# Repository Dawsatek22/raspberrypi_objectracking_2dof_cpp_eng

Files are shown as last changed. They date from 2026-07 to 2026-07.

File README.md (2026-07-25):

# raspberrypi_objectracking_2dof_cpp_eng
The second version of a Raspberry Pi c++ object tracking robot(link is here: https://github.com/Dawsatek22/raspberrypi_objectracking_1dof_cpp). This version  can now use the x and y direction.The tutorial videos are posted 1 month earlier on c/c++ exclusive on : https://vanillo.tv/v/18WrPnBuGD-. first before it is posted on youtube in 26 august: https://youtu.be/UmCWkWiB-DA.It is advised to read the eng_list.txt first before following the tutorial video instructions.

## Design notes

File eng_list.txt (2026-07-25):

playlist tutorial video:
00:05: Warnings and summaries
00:10 assembeling the board:
03:14 add the camera module
03:51 add the servo board
05:21 add the servos
15:31 Attach camera
16:56 Attach wires
18:58 turn on the power
19:34 test the robot
22:52  Finishing the robot

Warnings and summaries:

This is a english list for the Raspberry Pi 2 degrees of freedom tracking robot in c++ language,Most of the cad parts used are also possible(and more)at: https://openroboticplatform.com/ .if you are interested,Links for  tools and materials are more for reference than a nessecary link,
You can find the required tools else if you want,
The tutorial video instructions is explained in text so take that in mind,
If there is something wrong please reply if possible.

Required software:

opencv c++ version for the Raspberry Pi ( https://opencv.org/get-started/?utm_source=opcv&utm_medium=home ),lccv for Raspberry Pi camera ( https://github.com/kbarni/LCCV.git ),
PIPCA9685 software for the Raspberry Pi ( https://github.com/barulicm/PiPCA9685.git ),
vnc viewer for pc/laptop ( https://www.realvnc.com/en/connect/download/viewer/?lai_sr=0-4&lai_sl=l&lai_p=1&lai_na=488119 ),
vscode or other editor for c++ and cmake and Raspberry Pi (optional).
Recomended skills:
c/c++ programming,ssh into a Raspberry Pi with vnc viewer,
using opencv in c++,Aquiring 3d printed parts or making parts,
screwing parts together.Working with 5V power supplies.

1x pc/laptop
1x wifi access
1x micro sd card with Raspberry Pi os installed(newest recommended).
2x MG9685R servo motor ( https://www.google.com/aclk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 ).
1x Raspberry Pi 4 power supply ( https://www.kiwi-electronics.com/nl/raspberry-pi-boards-behuizingen-uitbreidingen-en-accessoires-59/raspberry-pi-45w-usb-c-power-supply-wit-eu-20344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 ).
1x Raspberry Pi 4 4gb or more board ( https://www.kiwi-electronics.com/nl/raspberry-pi-boards-behuizingen-uitbreidingen-en-accessoires-59/raspberry-pi-4-model-b-4gb-4268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 ).
1x Raspberry Pi camera module 2 ( https://www.kiwi-electronics.com/nl/raspberry-pi-boards-behuizingen-uitbreidingen-en-accessoires-59/raspberry-pi-camera-accessoires-133/raspberry-pi-camera-module-2-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 ).
1x Raspberry Pi Camera and Display Cable - 15 pin FFC flex - 30cm (https://www.tinytronics.nl/en/cables-and-connectors/cables-and-adapters/ffc/raspberry-pi-camera-cable-15-pin-fpc-flex-30cm).
1x Servo Driver HAT for Raspberry Pi - 16ch - 12-bit - I2C or PCA9685 board as alernative  ( https://www.kiwi-electronics.com/en/servo-driver-hat-for-raspberry-pi-16ch-12-bit-i2c-10373?country=NL ).
6x 20mm m/f dupont wires ( https://www.amazon.nl/Dupont-Jumper-Arduino-Raspberry-projects/dp/B09KGRM98K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 )
1x yellow object for testing like a dc tt motor wheel for example( https://www.tinytronics.nl/en/mechanics-and-actuators/parts/wheels/spare-wheel-auto-kit-diy )
1x m2.5 allen wrench
1x m3 allen wrench
1x m4 allen wr

Screws and bolts spacer:
4x m3x14mm allen screws
4x m4 nuts
2x m3x6mm allen screws

2x m3x12mm allen screws
10x m3x16mm allen screws
10 m3 nuts
4x m2.5x6mm allen screws
2x m2.5x10x6 standoff brass spacer
2x m2x8mm allen screws2x m2 nuts

Cad parts(pla recomended):
1x dt22-225-d22_cam_plate_100x160mm.stl
1x dt22-226-cam_2-sideways.stl
1x dt22-241-mg996r_bottomv3_ext1.stl
1x dt22-241-orp_extender_bend_v3.2.stl
1x dt22-241-orp_extender60mm_mg996r_v3.stl
1x dt22-241-mg996r_bottom_v3.stl
1x Radek_Janecka-172-RaspberryPi_holder.stl

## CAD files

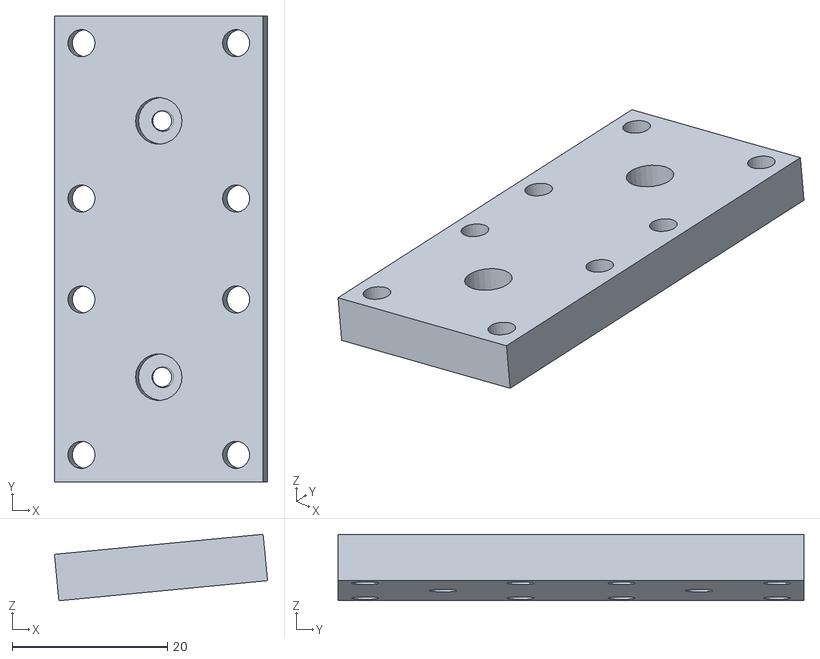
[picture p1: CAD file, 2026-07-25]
cad_parts/dt22-241-orp_extender60mm_mg996r_v3.stl
27.5 x 60.0 x 8.56

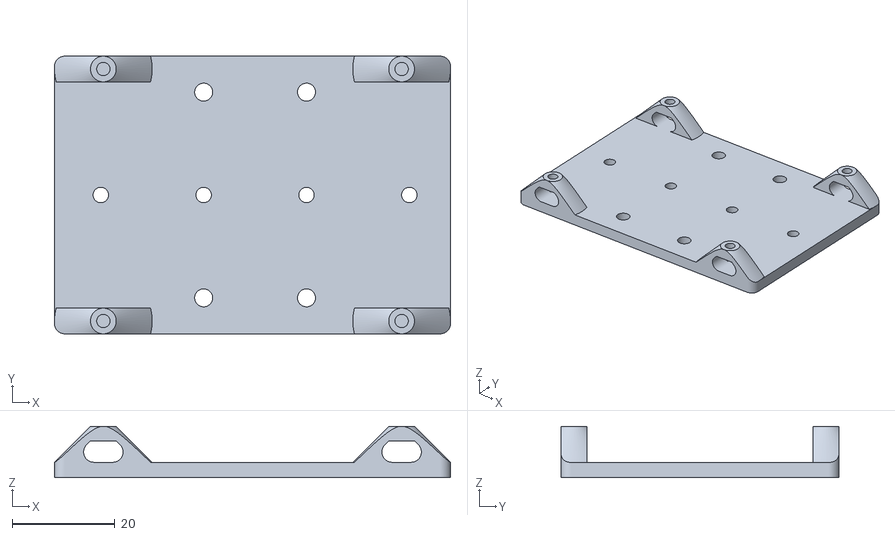
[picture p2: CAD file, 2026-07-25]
cad_parts/Radek_Janecka-172-RaspberryPi_holder.stl
77.0 x 54.0 x 10.0

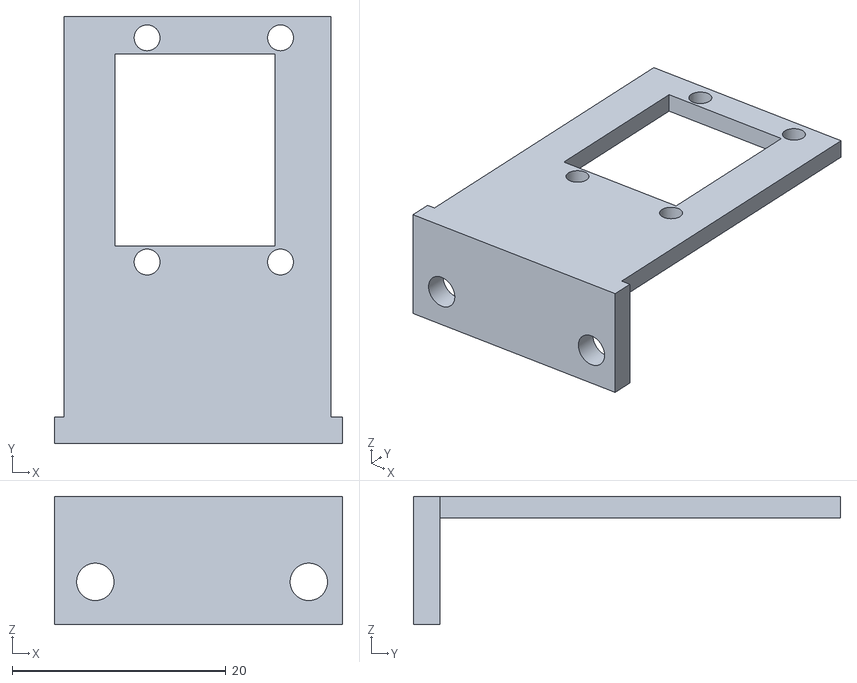
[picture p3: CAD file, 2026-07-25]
cad_parts/dt22-226-cam_2-sideways.stl
27.0 x 40.0 x 12.0

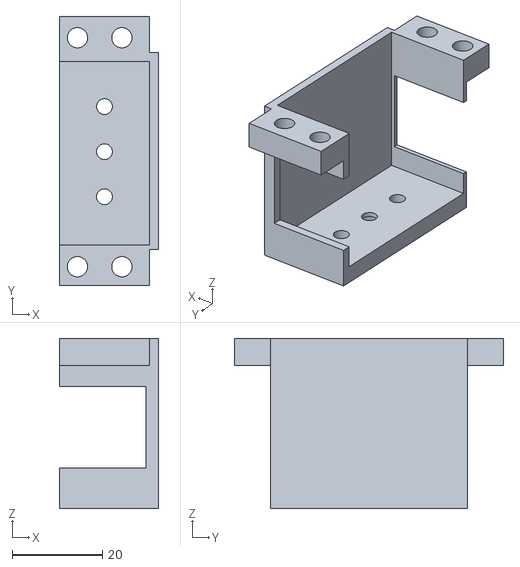
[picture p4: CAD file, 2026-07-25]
cad_parts/dt22-241-mg996r_bottom_v3.stl
22.0 x 59.7 x 37.7

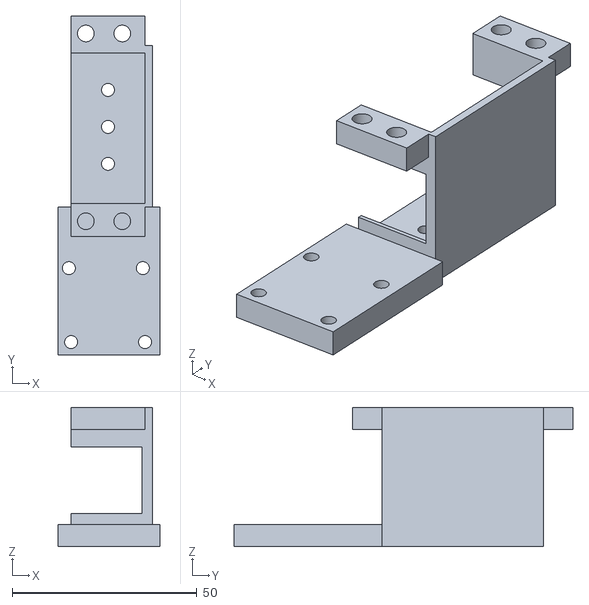
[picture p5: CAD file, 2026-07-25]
cad_parts/dt22-241-mg996r_bottomv3_ext1.stl
27.5 x 91.7 x 37.7

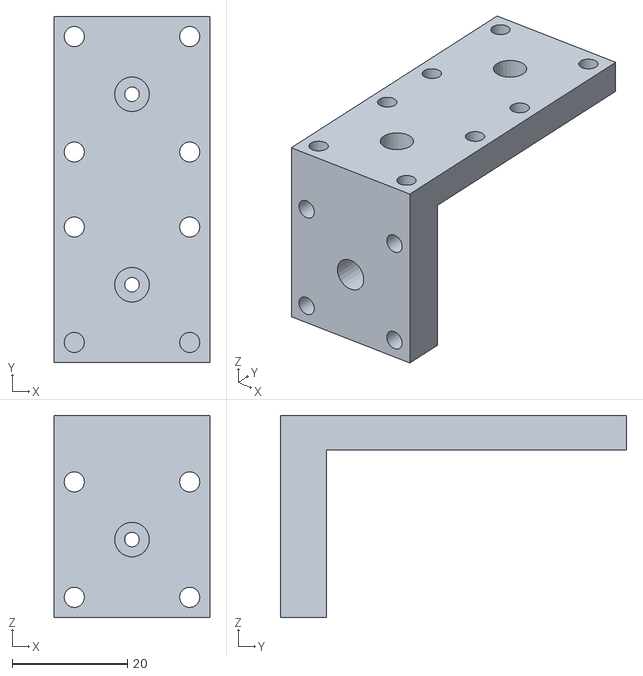
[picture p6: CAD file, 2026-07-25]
cad_parts/dt22-241-orp_extender_bend_v3.2.stl
27.0 x 60.0 x 35.0

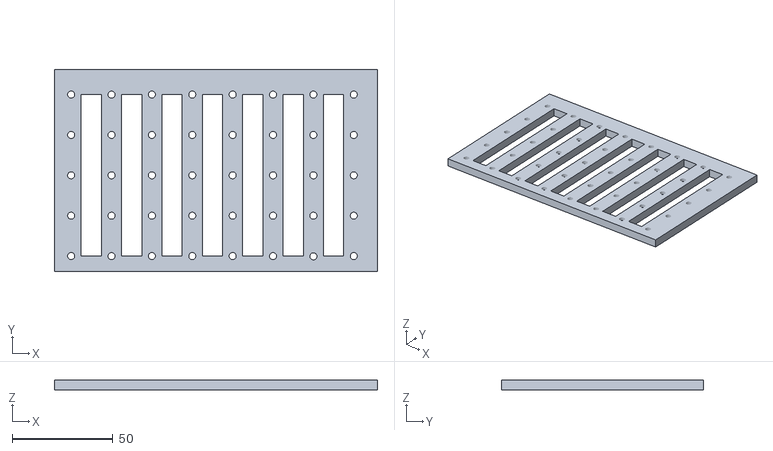
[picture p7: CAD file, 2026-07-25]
cad_parts/dt22-225-d22_cam_plate_100x160mm.stl
160.0 x 100.0 x 5.00
